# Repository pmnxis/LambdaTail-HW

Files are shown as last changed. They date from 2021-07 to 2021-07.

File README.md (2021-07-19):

# LambdaTail PCB
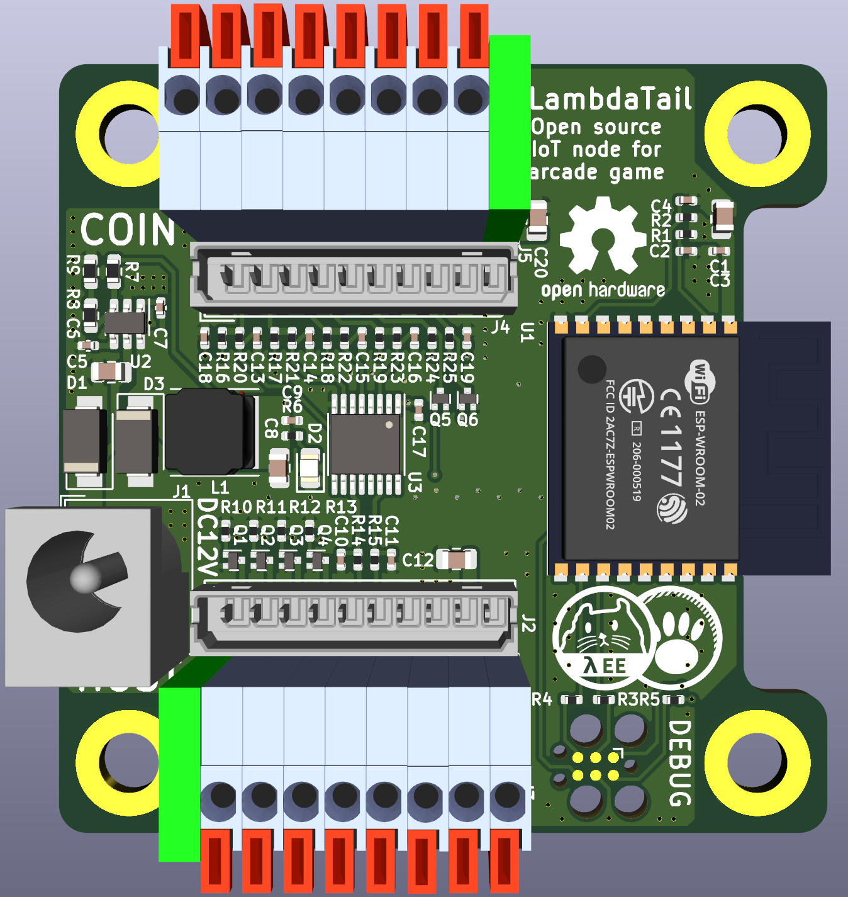
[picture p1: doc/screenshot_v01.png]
ex_screenshot

**Open source IoT node for arcade game**

The goal of this repository is to make **Rust** + **RISC-V** + **Kicad6** based hardware.
And IoT node should be published to large number of devices. So aimed to manufacture with low-cost with less-BOM.

## How works
Monitor vend side device such as paper or coin acceptor at top connector. And then reflect or modify signal to bottom side's connector. 

While monitor vend side, send signal to server or process something.

## Schematics
[Schematic](doc/LambdaTail-HW.pdf)

## Simplified characteristics
| Parameter | Min | Typ | Max | Unit | 
| --- | --- | --- | --- | --- |
| Voltage Power Supply | 4.5 | 12  | 16  | V  |
| Current Consumption  | 50  | 100 | 400 | mA |
| Dimenssion | | 55 x 55 x 16 | | mm

## Dependancy of footprint library
 - https://github.com/pmnxis/Lambda_KICAD5_LIB
 - https://github.com/espressif/kicad-libraries
 - Kicad 5.99 (Kicad 6) and Kicad 5 (legacy) default libraries.

## License
CERN-OHL-S-2.0 for Routing, Gerber, Schematic

Follow to original owner's license for footprint and related things.

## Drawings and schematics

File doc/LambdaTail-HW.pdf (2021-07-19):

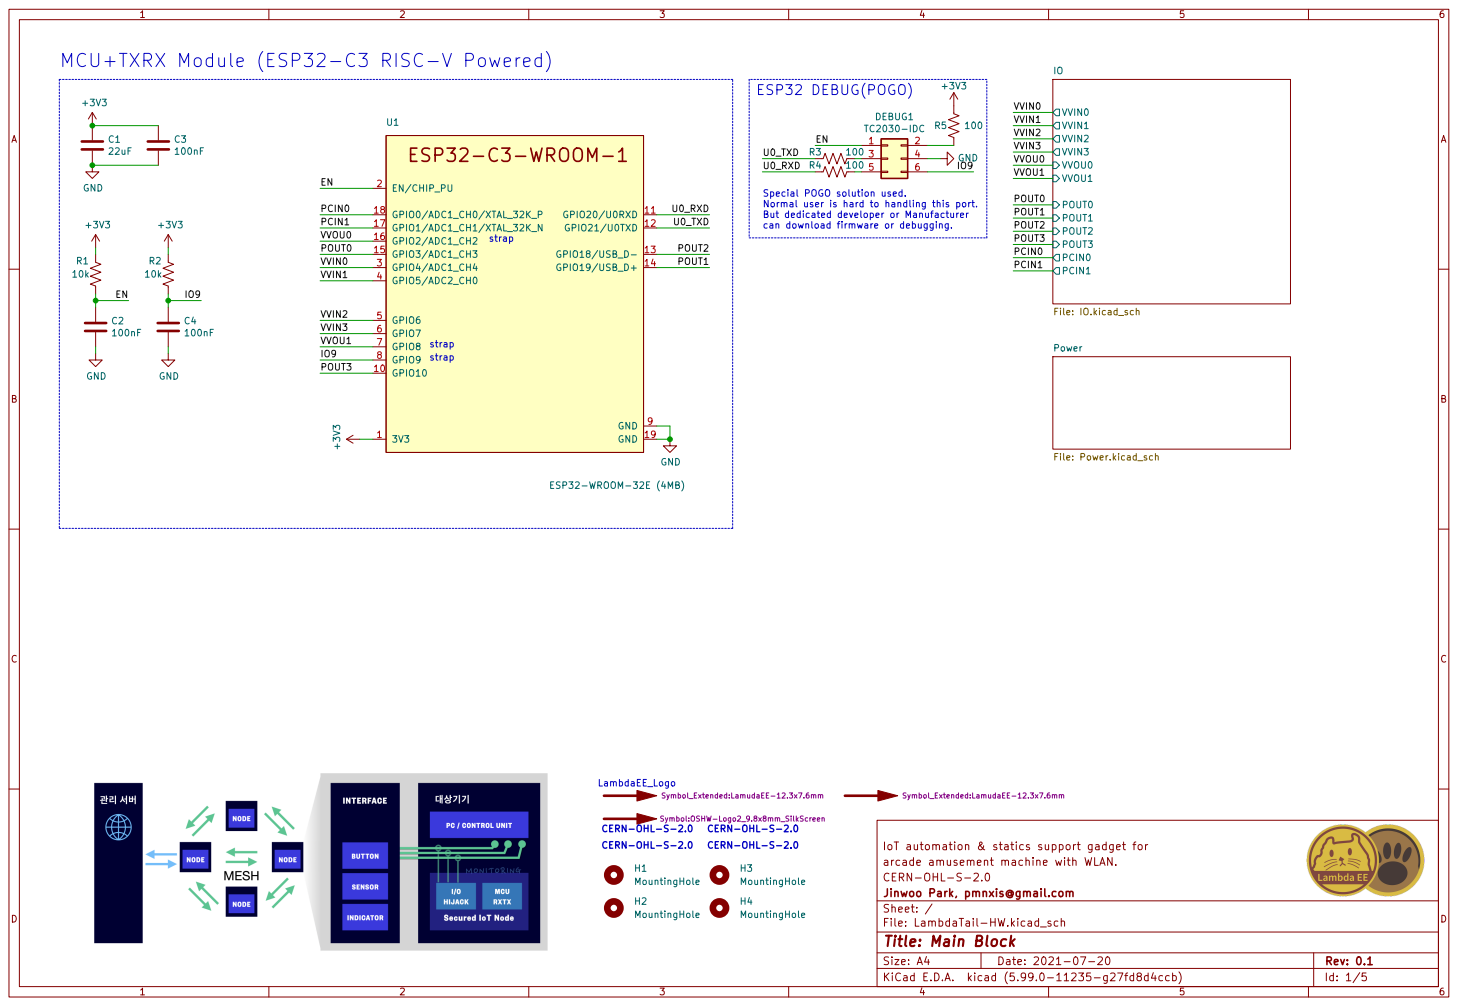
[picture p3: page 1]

strap MCU+TXRX Module (ESP32-C3 RISC-V Powered)

Special POGO solution used.
Normal user is hard to handling this port.
But dedicated developer or Manufacturer

can download firmware or debugging. strap

IoT automation & statics support gadget for arcade amusement machine with WLAN. CERN-OHL-S-2.0

File: LambdaTail-HW.kicad_sch Sheet: / Jinwoo Park, pmnxis@gmail.com

Id: 1/5 Title: Main Block

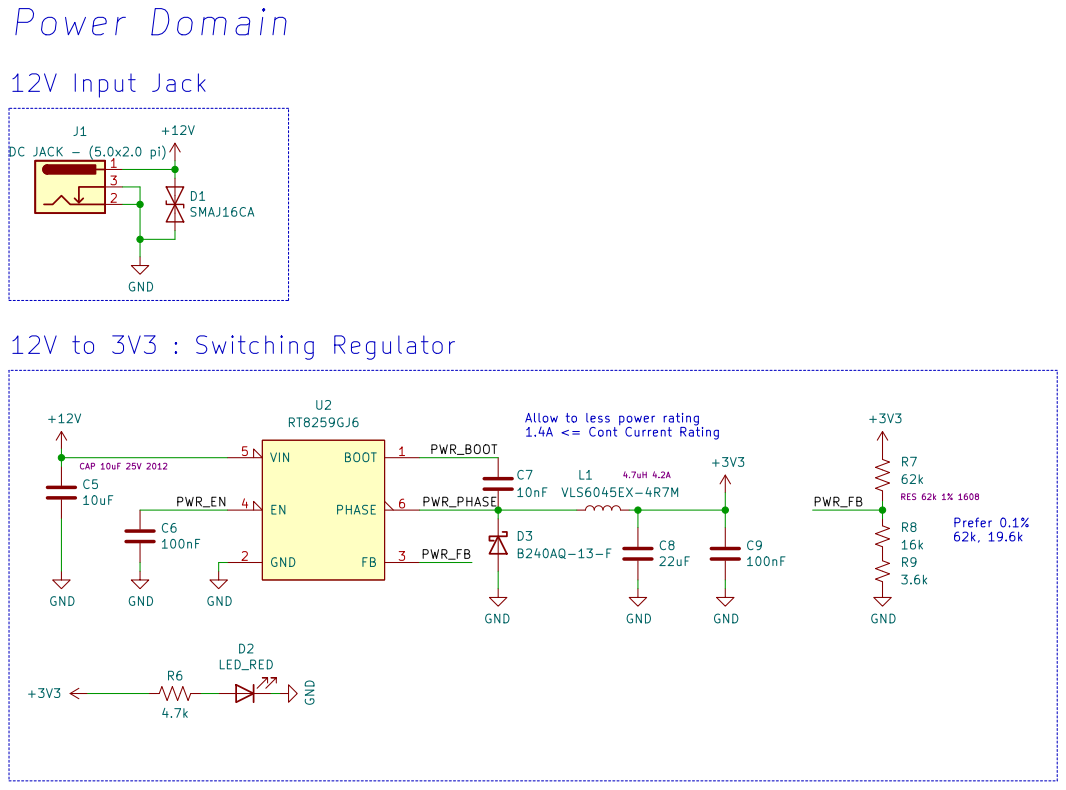
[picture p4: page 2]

Allow to less power rating
1.4A <= Cont Current Rating

IoT automation & statics support gadget for arcade amusement machine with WLAN. CERN-OHL-S-2.0

File: Power.kicad_sch Sheet: /Power/ Jinwoo Park, pmnxis@gmail.com

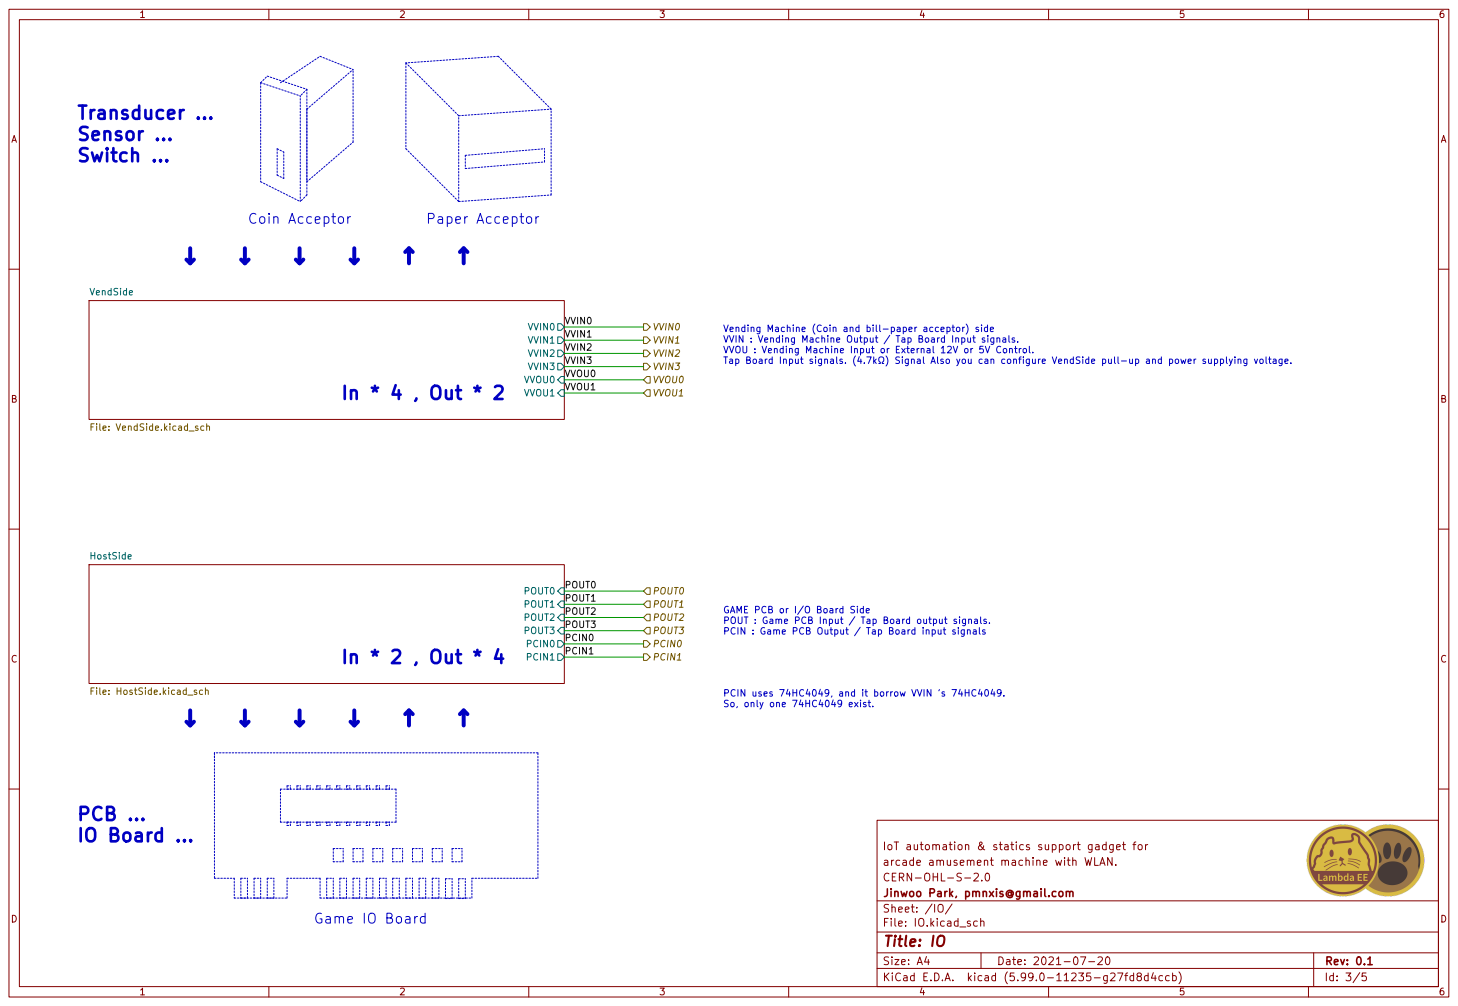
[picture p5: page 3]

VVIN : Vending Machine Output / Tap Board Input signals.
VVOU : Vending Machine Input or External 12V or 5V Control.

PCIN : Game PCB Output / Tap Board input signals PCIN uses 74HC4049, and it borrow VVIN 's 74HC4049. So, only one 74HC4049 exist.

IoT automation & statics support gadget for arcade amusement machine with WLAN. CERN-OHL-S-2.0

File: IO.kicad_sch Sheet: /IO/ Jinwoo Park, pmnxis@gmail.com

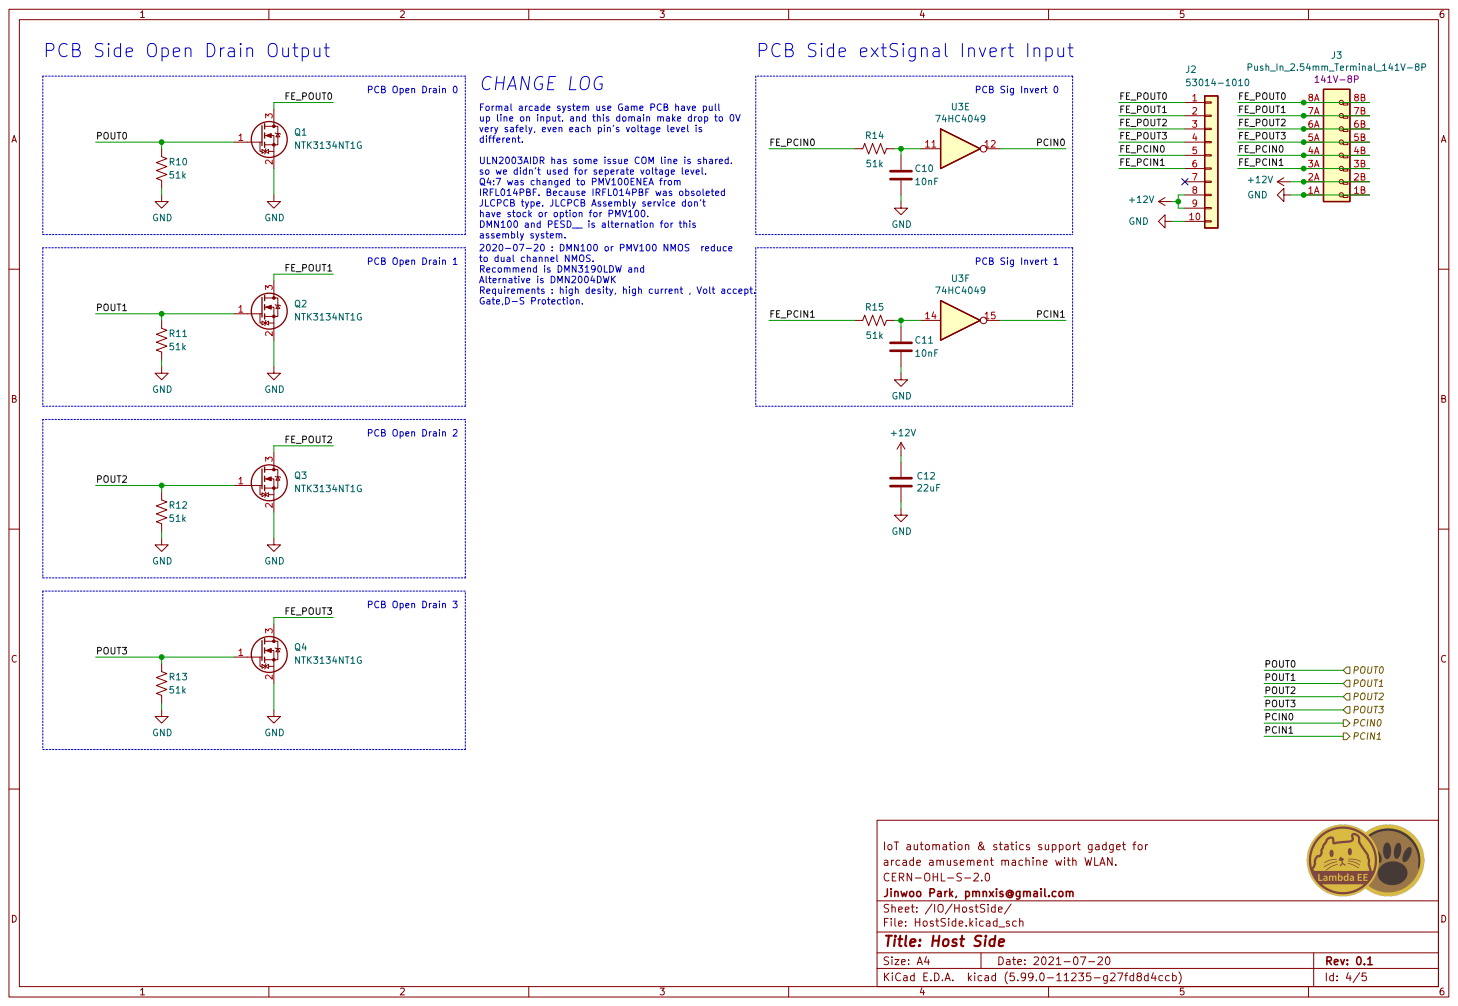
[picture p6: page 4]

to dual channel NMOS. Recommend is DMN3190LDW and Alternative is DMN2004DWK Requirements : high desity, high current , Volt accept. Gate,D-S Protection. PCB Side Open Drain Output

PCB Side extSignal Invert Input

FE_POUT2 FE_POUT3 FE_PCIN0 POUT1 POUT0 PCIN1 Formal arcade system use Game PCB have pull
up line on input. and this domain make drop to 0V
very safely, even each pin's voltage level is different. ULN2003AIDR has some issue COM line is shared. so we didn't used for seperate voltage level.

Q4:7 was changed to PMV100ENEA from
IRFL014PBF. Because IRFL014PBF was obsoleted JLCPCB type. JLCPCB Assembly service don't

have stock or option for PMV100. DMN100 and PESD__ is alternation for this assembly system.

IoT automation & statics support gadget for arcade amusement machine with WLAN. CERN-OHL-S-2.0

File: HostSide.kicad_sch Sheet: /IO/HostSide/ Jinwoo Park, pmnxis@gmail.com

Id: 4/5 Title: Host Side

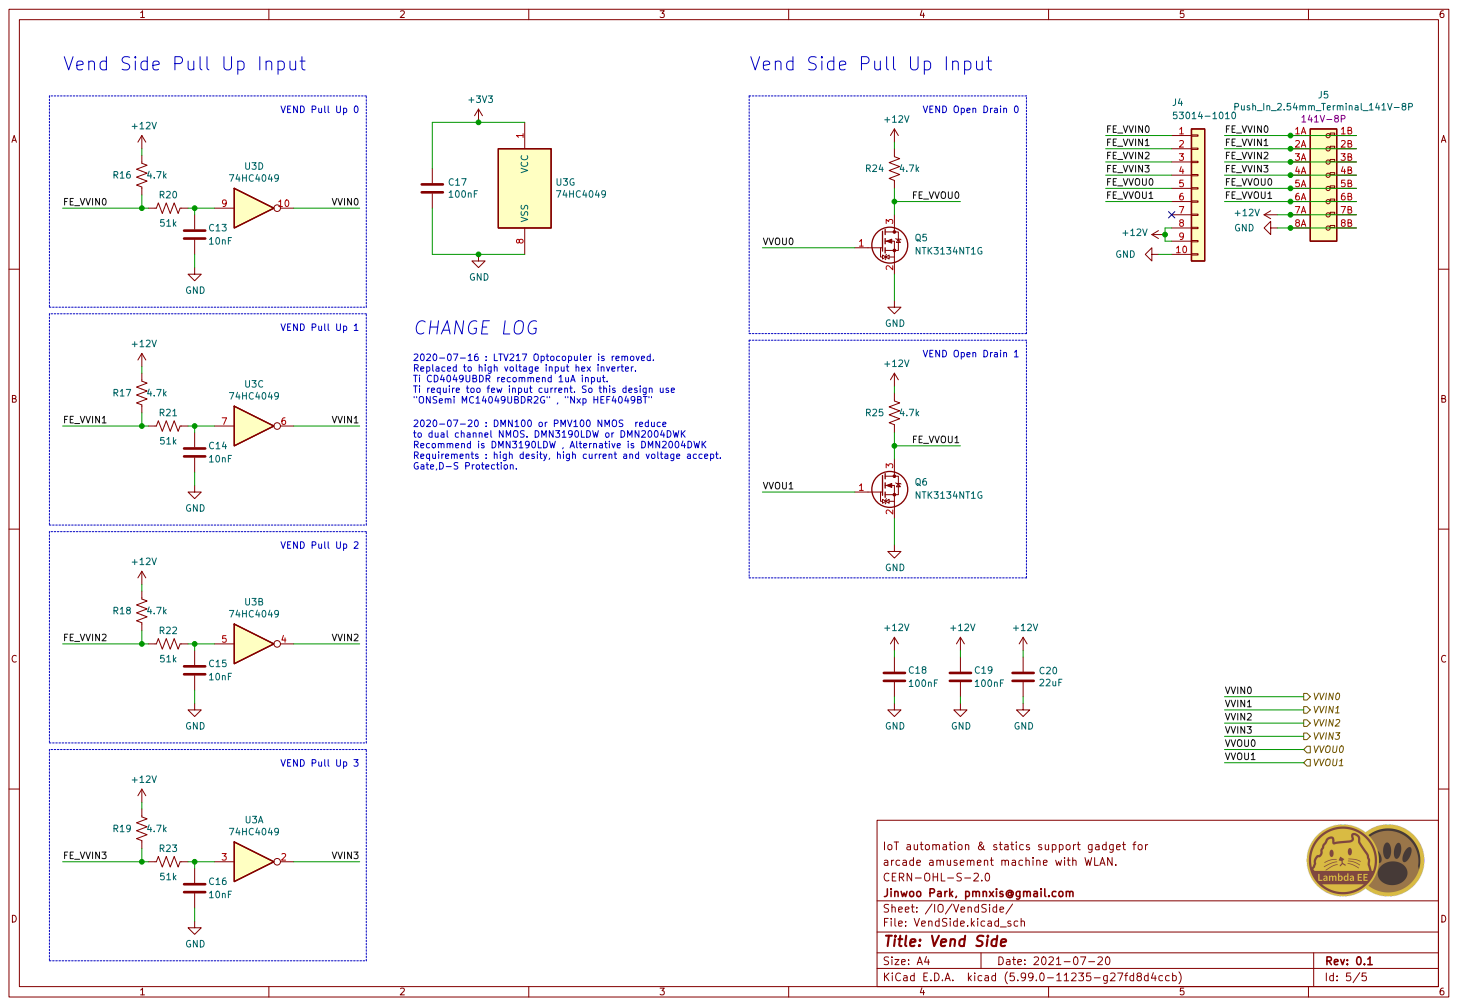
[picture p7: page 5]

Vend Side Pull Up Input

FE_VVIN0 FE_VVIN1 FE_VVIN2 FE_VVOU1 Vend Side Pull Up Input

to dual channel NMOS. DMN3190LDW or DMN2004DWK Recommend is DMN3190LDW , Alternative is DMN2004DWK Requirements : high desity, high current and voltage accept. Gate,D-S Protection. VEND Pull Up 0

2020-07-16 : LTV217 Optocopuler is removed.
Replaced to high voltage input hex inverter.
Ti CD4049UBDR recommend 1uA input.
Ti require too few input current. So this design use
"ONSemi MC14049UBDR2G" , "Nxp HEF4049BT" 2020-07-20 : DMN100 or PMV100 NMOS reduce

IoT automation & statics support gadget for arcade amusement machine with WLAN. CERN-OHL-S-2.0 C14

File: VendSide.kicad_sch Sheet: /IO/VendSide/ Jinwoo Park, pmnxis@gmail.com

Id: 5/5 Title: Vend Side

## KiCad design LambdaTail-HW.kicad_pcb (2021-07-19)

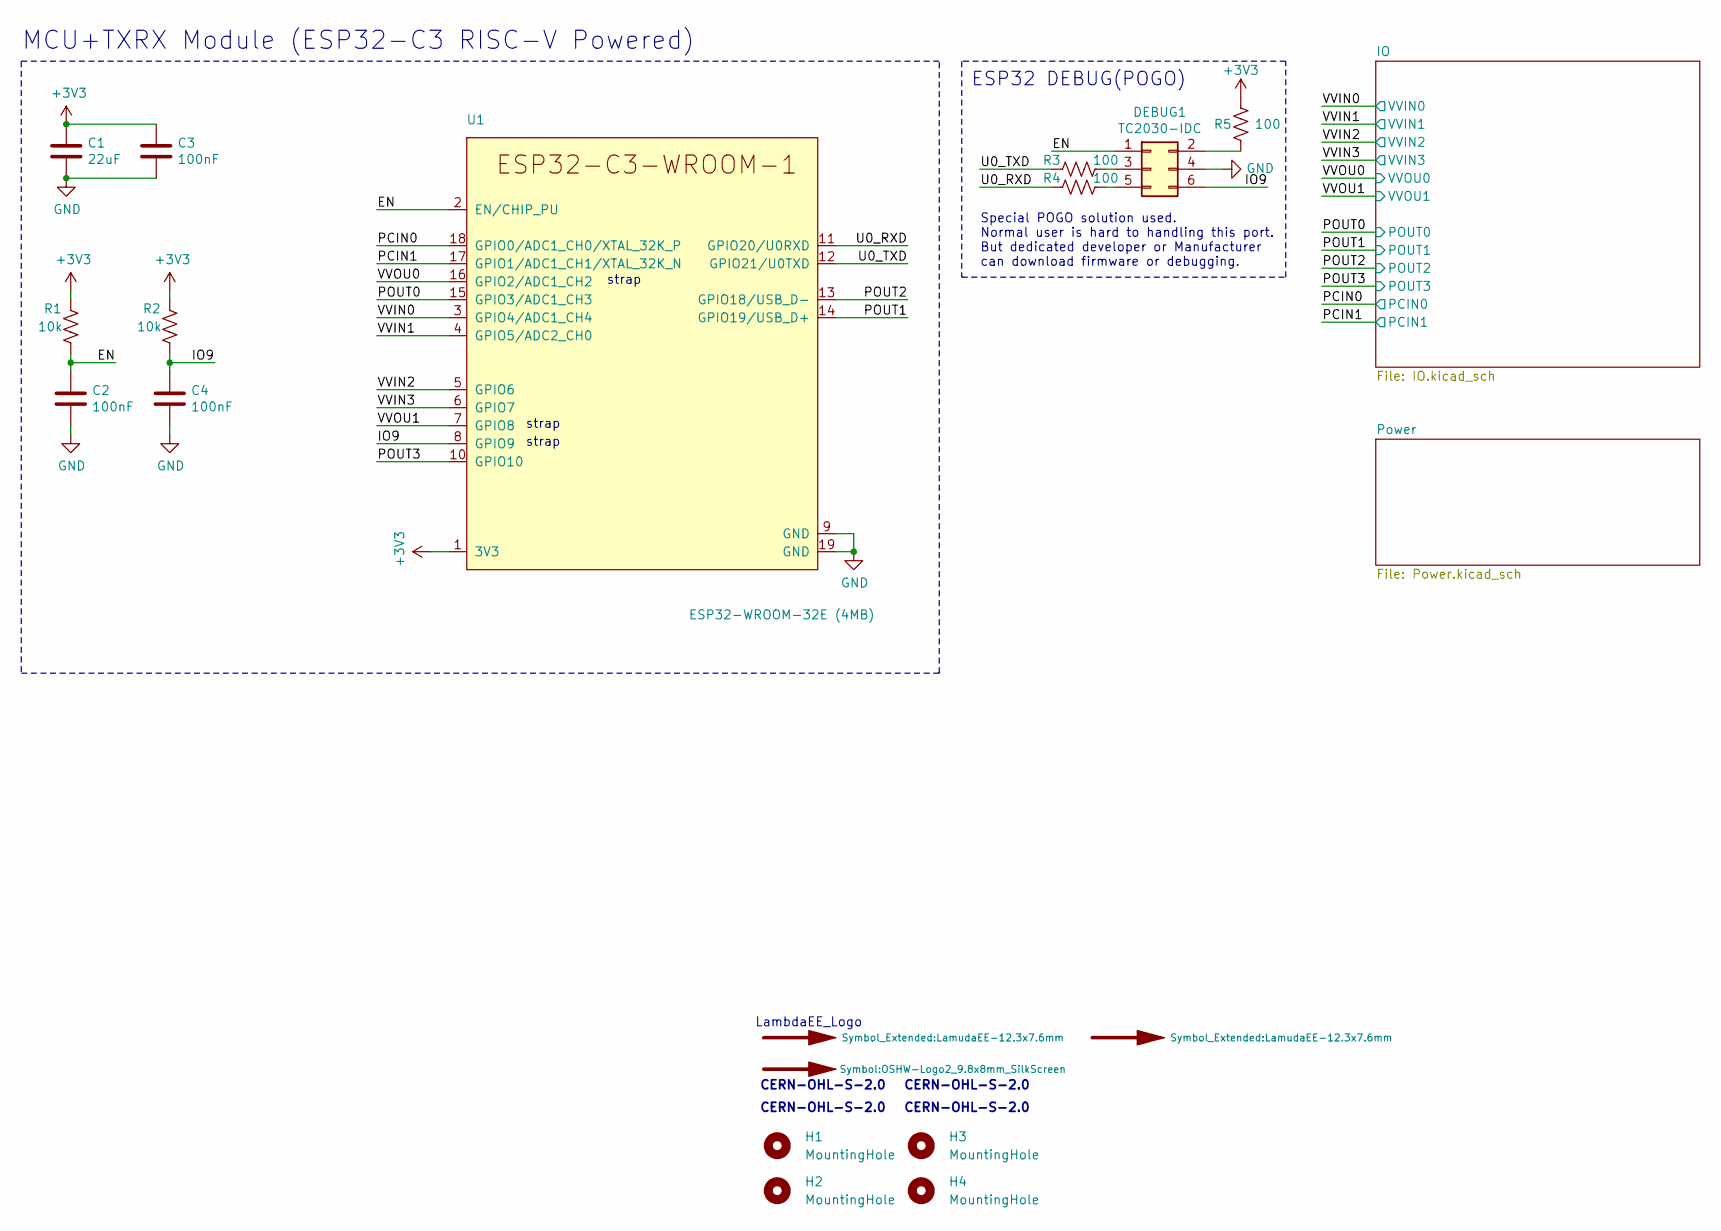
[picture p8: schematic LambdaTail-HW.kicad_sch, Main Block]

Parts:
C1: 22uF; C_0805_2012Metric; MFR.Part# CL21A226MAQNNNE; LCSC Part C45783
C2, C3, C4: 100nF; C_0402_1005Metric; MFR.Part# CL05B104KO5NNNC; LCSC Part C1525
DEBUG1: TC2030-IDC; Tag-Connect_TC2030-IDC-FP_2x03_P1.27mm_Vertical
H1, H2, H3, H4: MountingHole; MountingHole_4.3mm_M4_ISO7380_Pad_TopBottom
R1, R2: 10k; R_0402_1005Metric; MFR.Part# 0402WGF1002TCE; LCSC Part C25744
R3, R4, R5: 100; R_0402_1005Metric; MFR.Part# 0402WGF1000TCE; LCSC Part C25076
SYM1, SYM3: SYM_Arrow_XLarge; LamudaEE-12.3x7.6mm
SYM2: SYM_Arrow_XLarge; OSHW-Logo2_9.8x8mm_SilkScreen
U1: ESP32-WROOM-32E (4MB); ESP32-C3-WROOM-1; MFR.Part# ESP32-WROOM-32E (4MB)

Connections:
+3V3: C1.1, C3.1, R1.1, R2.1, R5.1, U1.1 (3V3); also elsewhere on the board
/EN: C2.1, DEBUG1.1, R1.2, U1.2 (EN/CHIP_PU)
/IO9: C4.1, DEBUG1.6, R2.2, U1.8 (GPIO9)
/PCIN0: U1.18 (GPIO0/ADC1_CH0/XTAL_32K_P); also elsewhere on the board
/PCIN1: U1.17 (GPIO1/ADC1_CH1/XTAL_32K_N); also elsewhere on the board
/POUT0: U1.15 (GPIO3/ADC1_CH3); also elsewhere on the board
/POUT1: U1.14 (GPIO19/USB_D+); also elsewhere on the board
/POUT2: U1.13 (GPIO18/USB_D-); also elsewhere on the board
/POUT3: U1.10 (GPIO10); also elsewhere on the board
/U0_RXD: R4.1, U1.11 (GPIO20/U0RXD)
/U0_TXD: R3.1, U1.12 (GPIO21/U0TXD)
/VVIN0: U1.3 (GPIO4/ADC1_CH4); also elsewhere on the board
/VVIN1: U1.4 (GPIO5/ADC2_CH0); also elsewhere on the board
/VVIN2: U1.5 (GPIO6); also elsewhere on the board
/VVIN3: U1.6 (GPIO7); also elsewhere on the board
/VVOU0: U1.16 (GPIO2/ADC1_CH2); also elsewhere on the board
/VVOU1: U1.7 (GPIO8); also elsewhere on the board
GND: C1.2, C2.2, C3.2, C4.2, DEBUG1.4, U1.9 (GND), U1.19 (GND); also elsewhere on the board
unnamed: DEBUG1.2, R5.2
unnamed: DEBUG1.3, R3.2
unnamed: DEBUG1.5, R4.2

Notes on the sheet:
MCU+TXRX Module (ESP32-C3 RISC-V Powered)
strap
LambdaEE_Logo
CERN-OHL-S-2.0
ESP32 DEBUG(POGO)
Special POGO solution used. Normal user is hard to handling this port. But dedicated developer or Manufacturer can download firmware or debugging.

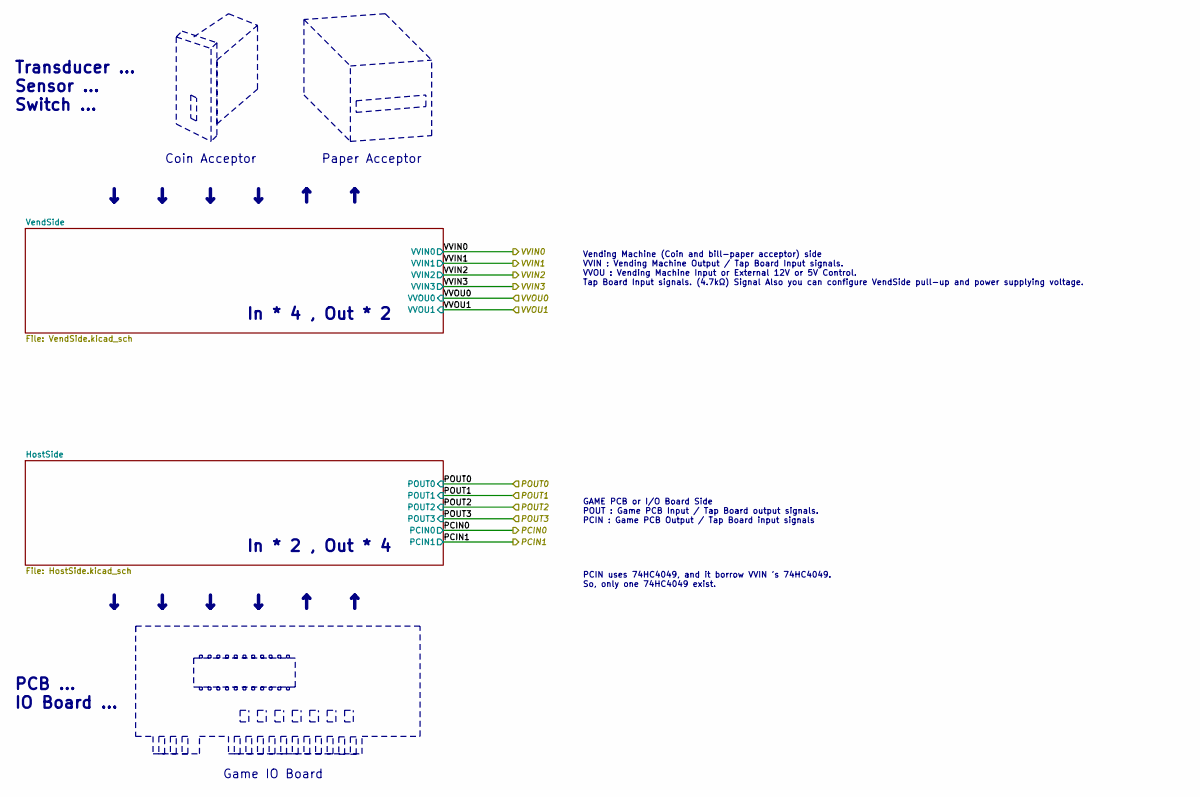
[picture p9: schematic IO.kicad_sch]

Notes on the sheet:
Transducer ... Sensor ... Switch ...
PCB ... IO Board ...
Coin Acceptor
Game IO Board
In * 4 , Out * 2
In * 2 , Out * 4
Paper Acceptor
↓ ↓ ↓ ↓ ↑ ↑
Vending Machine (Coin and bill-paper acceptor) side VVIN : Vending Machine Output / Tap Board Input signals. VVOU : Vending Machine Input or External 12V or 5V Control. Tap Board Input signals. (4.7kΩ) Signal Also you can configure VendSide pull-up and power supplying voltage.
GAME PCB or I/O Board Side POUT : Game PCB Input / Tap Board output signals. PCIN : Game PCB Output / Tap Board input signals
PCIN uses 74HC4049, and it borrow VVIN 's 74HC4049. So, only one 74HC4049 exist.

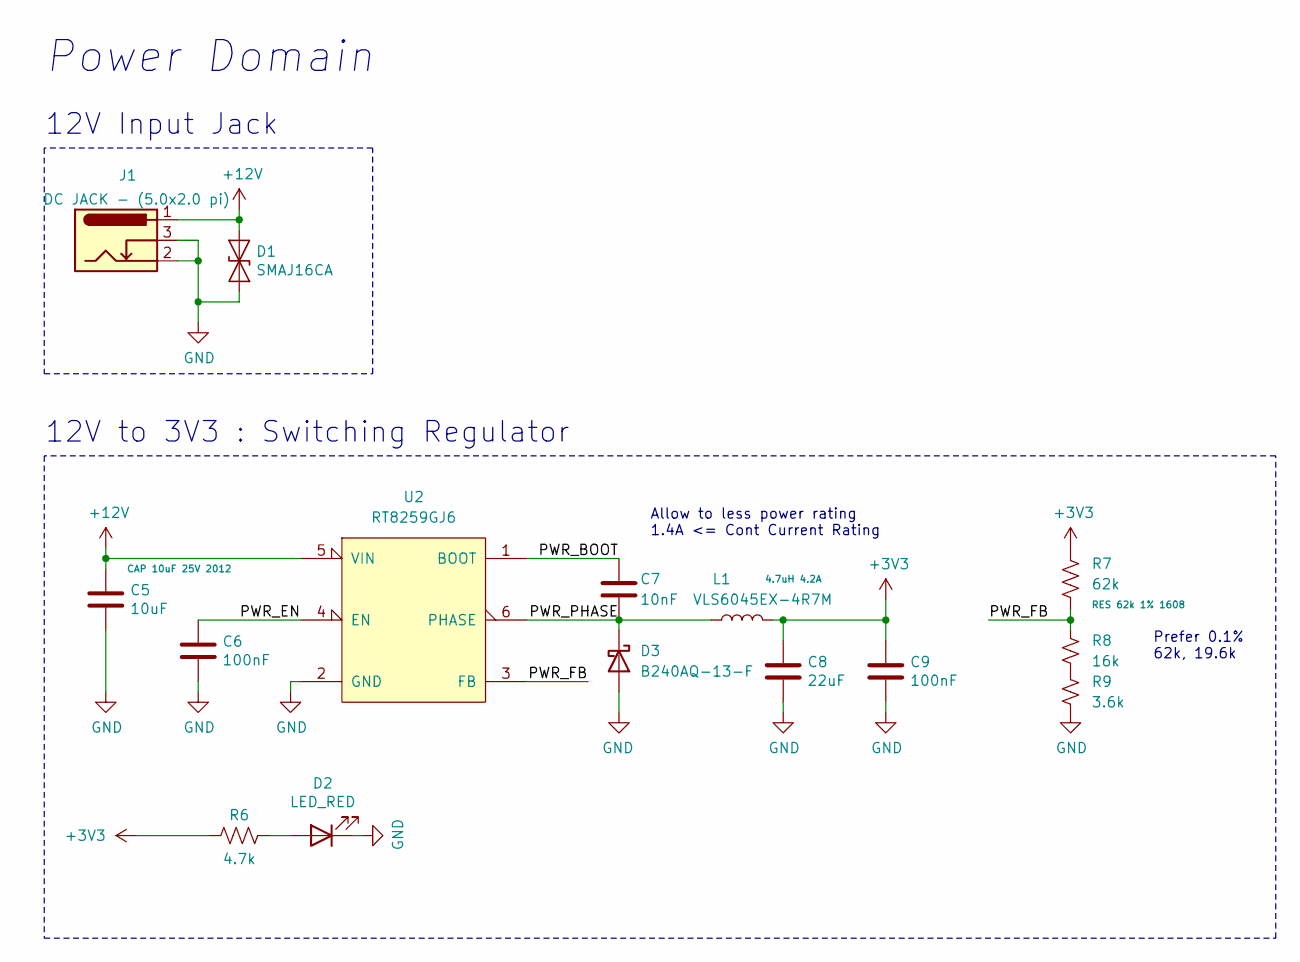
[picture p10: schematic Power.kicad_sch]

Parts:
C5: 10uF; C_0805_2012Metric; MFR.Part# CL21A106KAYNNNE; LCSC Part C15850
C6, C9: 100nF; C_0402_1005Metric; MFR.Part# CL05B104KO5NNNC; LCSC Part C1525
C7: 10nF; C_0402_1005Metric; MFR.Part# CL05B103KB5NNNC; LCSC Part C15195
C8: 22uF; C_0805_2012Metric; MFR.Part# CL21A226MAQNNNE; LCSC Part C45783
D1: SMAJ16CA; D_SMA; MFR.Part# SMAJ16CA; LCSC Part C135970
D2: LED_RED; LED_0805_2012Metric; MFR.Part# FC-2012HRK-620D; LCSC Part C84256
D3: B240AQ-13-F; D_SMA
J1: DC JACK - (5.0x2.0 pi); BarrelJack_General_DC-012-2-5A-2.0mm; MFR.Part# DC-005 5.5-2.0MM; LCSC Part C16214
L1: VLS6045EX-4R7M; L_TDK_VLS6045EX; MFR.Part# VLS6045EX-4R7M; LCSC Part C307880
R6: 4.7k; R_0402_1005Metric; MFR.Part# 0402WGF4701TCE; LCSC Part C25900
R7: 62k; R_0603_1608Metric; MFR.Part# 0603WAF6202T5E; LCSC Part C23221
R8: 16k; R_0603_1608Metric; MFR.Part# 0603WAF1602T5E; LCSC Part C22818
R9: 3.6k; R_0603_1608Metric; MFR.Part# 0603WAF3601T5E; LCSC Part C22980
U2: RT8259GJ6; TSOT-23-6; MFR.Part# RT8259GJ6; LCSC Part C130809

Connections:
+3V3: C8.1, C9.1, L1.2, R6.1, R7.1; also elsewhere on the board
+12V: C5.1, D1.1 (A1), J1.1, U2.5 (VIN); also elsewhere on the board
/Power/PWR_BOOT: C7.1, U2.1 (BOOT)
/Power/PWR_EN: C6.1, U2.4 (EN)
/Power/PWR_FB: R7.2, R8.1, U2.3 (FB)
/Power/PWR_PHASE: C7.2, D3.1 (K), L1.1, U2.6 (PHASE)
GND: C5.2, C6.2, C8.2, C9.2, D1.2 (A2), D2.1 (K), D3.2 (A), J1.2, J1.3, R9.2, U2.2 (GND); also elsewhere on the board
unnamed: D2.2 (A), R6.2
unnamed: R8.2, R9.1

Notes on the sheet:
Power Domain
12V Input Jack
12V to 3V3 : Switching Regulator
Allow to less power rating 1.4A <= Cont Current Rating
Prefer 0.1% 62k, 19.6k

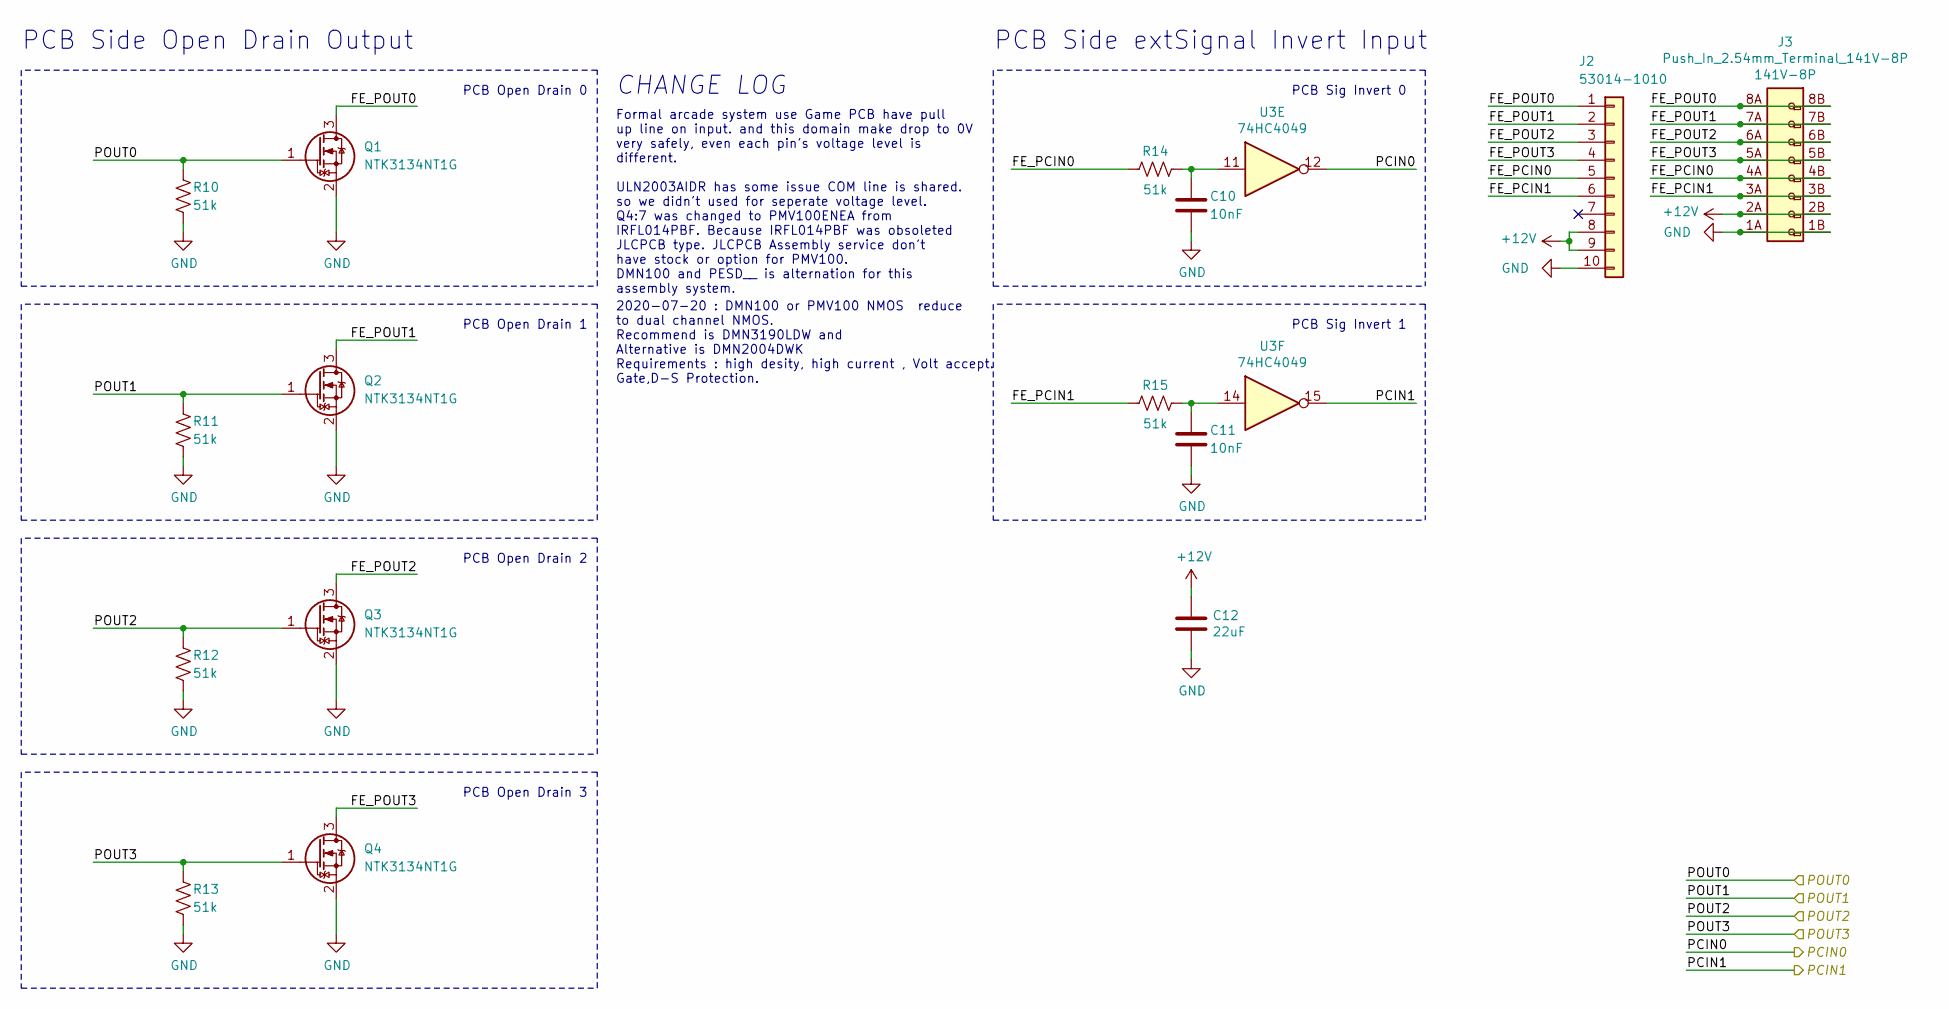
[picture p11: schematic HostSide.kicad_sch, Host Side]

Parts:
C10, C11: 10nF; C_0402_1005Metric; MFR.Part# CL05B103KB5NNNC; LCSC Part C15195
C12: 22uF; C_0805_2012Metric; MFR.Part# CL21A226MAQNNNE; LCSC Part C45783
J2: 53014-1010; Molex_MicroBlade_53014-1000_1x10_P2.00mm_Vertical; MFR.Part# 53014-1010
J3: Push_In_2.54mm_Terminal_141V-8P; TERMINAL_141V-8P; MFR.Part# 141V-8P
Q1, Q2, Q3, Q4: NTK3134NT1G; SOT-723; MFR.Part# NTK3134NT1G; LCSC Part C97777
R10, R11, R12, R13, R14, R15: 51k; R_0402_1005Metric; MFR.Part# 0402WGF5102TCE; LCSC Part C25794
U3: 74HC4049; TSSOP-16_4.4x5mm_P0.65mm; MFR.Part# MC14049UBDTR2GOS

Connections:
+12V: C12.1, J2.8, J2.9, J3.2A, J3.2B; also elsewhere on the board
/IO/HostSide/FE_PCIN0: J2.5, J3.4A, J3.4B, R14.1
/IO/HostSide/FE_PCIN1: J2.6, J3.3A, J3.3B, R15.1
/IO/HostSide/FE_POUT0: J2.1, J3.8A, J3.8B, Q1.3 (D)
/IO/HostSide/FE_POUT1: J2.2, J3.7A, J3.7B, Q2.3 (D)
/IO/HostSide/FE_POUT2: J2.3, J3.6A, J3.6B, Q3.3 (D)
/IO/HostSide/FE_POUT3: J2.4, J3.5A, J3.5B, Q4.3 (D)
/PCIN0: U3.12; also elsewhere on the board
/PCIN1: U3.15; also elsewhere on the board
/POUT0: Q1.1 (G), R10.1; also elsewhere on the board
/POUT1: Q2.1 (G), R11.1; also elsewhere on the board
/POUT2: Q3.1 (G), R12.1; also elsewhere on the board
/POUT3: Q4.1 (G), R13.1; also elsewhere on the board
GND: C10.2, C11.2, C12.2, J2.10, J3.1A, J3.1B, Q1.2 (S), Q2.2 (S), Q3.2 (S), Q4.2 (S), R10.2, R11.2, R12.2, R13.2; also elsewhere on the board
unnamed: C10.1, R14.2, U3.11
unnamed: C11.1, R15.2, U3.14

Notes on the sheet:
PCB Side Open Drain Output
PCB Open Drain 0
PCB Open Drain 1
PCB Open Drain 2
PCB Open Drain 3
CHANGE LOG
Formal arcade system use Game PCB have pull up line on input. and this domain make drop to 0V very safely, even each pin's voltage level is different. ULN2003AIDR has some issue COM line is shared. so we didn't used for seperate voltage level. Q4:7 was changed to PMV100ENEA from IRFL014PBF. Because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
2020-07-20 : DMN100 or PMV100 NMOS reduce to dual channel NMOS. Recommend is DMN3190LDW and Alternative is DMN2004DWK Requirements : high desity, high current , Volt accept. Gate,D-S Protection.
PCB Side extSignal Invert Input
PCB Sig Invert 0
PCB Sig Invert 1

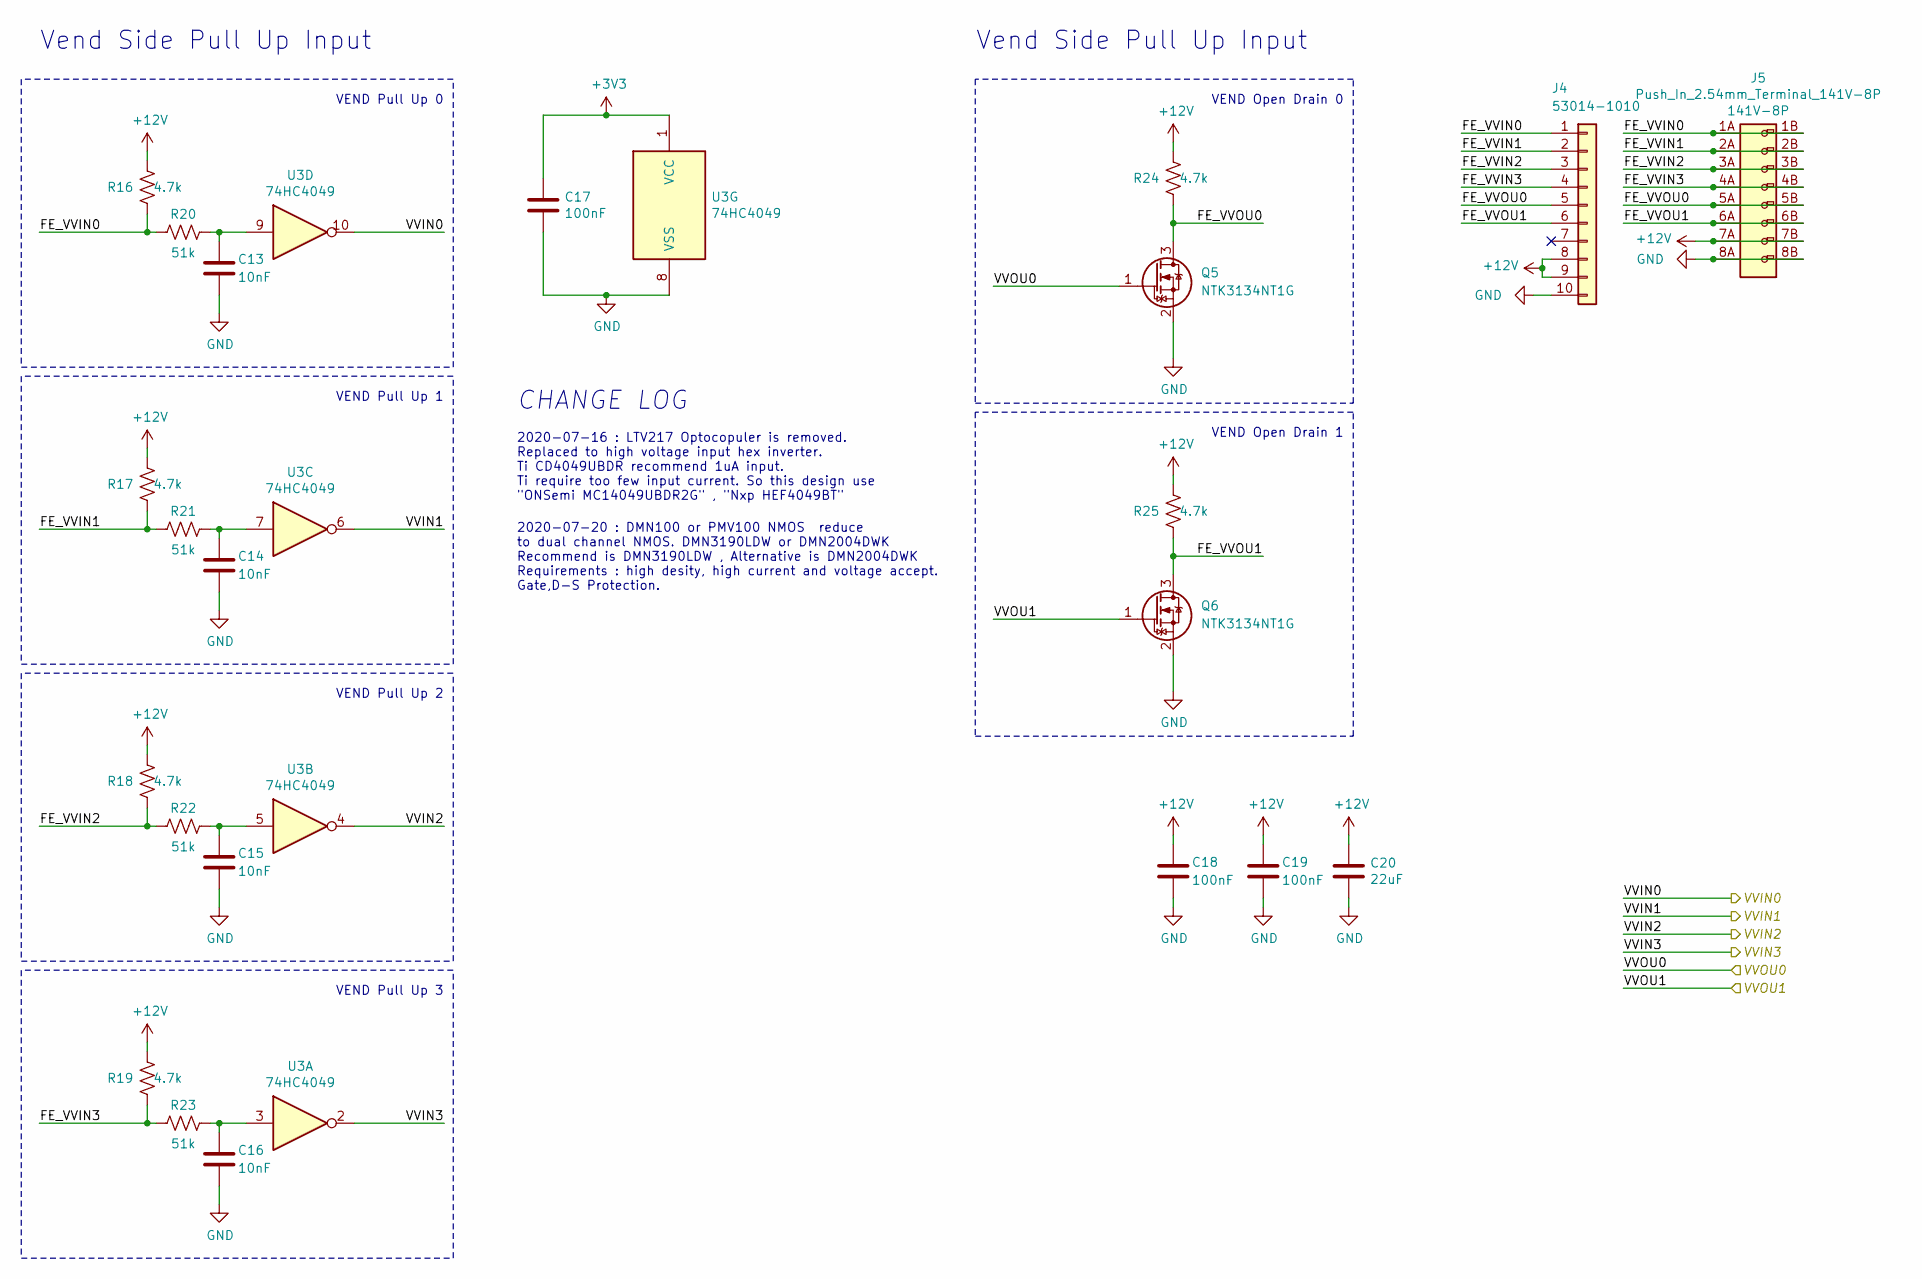
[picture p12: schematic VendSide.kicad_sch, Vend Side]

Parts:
C13, C14, C15, C16: 10nF; C_0402_1005Metric; MFR.Part# CL05B103KB5NNNC; LCSC Part C15195
C17, C18, C19: 100nF; C_0402_1005Metric; MFR.Part# CL05B104KO5NNNC; LCSC Part C1525
C20: 22uF; C_0805_2012Metric; MFR.Part# CL21A226MAQNNNE; LCSC Part C45783
J4: 53014-1010; Molex_MicroBlade_53014-1000_1x10_P2.00mm_Vertical; MFR.Part# 53014-1010
J5: Push_In_2.54mm_Terminal_141V-8P; TERMINAL_141V-8P; MFR.Part# 141V-8P
Q5, Q6: NTK3134NT1G; SOT-723; MFR.Part# NTK3134NT1G; LCSC Part C97777
R16, R17, R18, R19, R24, R25: 4.7k; R_0402_1005Metric; MFR.Part# 0402WGF4701TCE; LCSC Part C25900
R20, R21, R22, R23: 51k; R_0402_1005Metric; MFR.Part# 0402WGF5102TCE; LCSC Part C25794
U3: 74HC4049; TSSOP-16_4.4x5mm_P0.65mm; MFR.Part# MC14049UBDTR2GOS

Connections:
+3V3: C17.1, U3.1 (VCC); also elsewhere on the board
+12V: C18.1, C19.1, C20.1, J4.8, J4.9, J5.7A, J5.7B, R16.2, R17.2, R18.2, R19.2, R24.2, R25.2; also elsewhere on the board
/IO/VendSide/FE_VVIN0: J4.1, J5.1A, J5.1B, R16.1, R20.1
/IO/VendSide/FE_VVIN1: J4.2, J5.2A, J5.2B, R17.1, R21.1
/IO/VendSide/FE_VVIN2: J4.3, J5.3A, J5.3B, R18.1, R22.1
/IO/VendSide/FE_VVIN3: J4.4, J5.4A, J5.4B, R19.1, R23.1
/IO/VendSide/FE_VVOU0: J4.5, J5.5A, J5.5B, Q5.3 (D), R24.1
/IO/VendSide/FE_VVOU1: J4.6, J5.6A, J5.6B, Q6.3 (D), R25.1
/VVIN0: U3.10; also elsewhere on the board
/VVIN1: U3.6; also elsewhere on the board
/VVIN2: U3.4; also elsewhere on the board
/VVIN3: U3.2; also elsewhere on the board
/VVOU0: Q5.1 (G); also elsewhere on the board
/VVOU1: Q6.1 (G); also elsewhere on the board
GND: C13.2, C14.2, C15.2, C16.2, C17.2, C18.2, C19.2, C20.2, J4.10, J5.8A, J5.8B, Q5.2 (S), Q6.2 (S), U3.8 (VSS); also elsewhere on the board
unnamed: C13.1, R20.2, U3.9
unnamed: C14.1, R21.2, U3.7
unnamed: C15.1, R22.2, U3.5
unnamed: C16.1, R23.2, U3.3

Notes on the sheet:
Vend Side Pull Up Input
VEND Pull Up 0
VEND Pull Up 1
VEND Pull Up 2
VEND Pull Up 3
CHANGE LOG
2020-07-16 : LTV217 Optocopuler is removed. Replaced to high voltage input hex inverter. Ti CD4049UBDR recommend 1uA input. Ti require too few input current. So this design use "ONSemi MC14049UBDR2G" , "Nxp HEF4049BT"
2020-07-20 : DMN100 or PMV100 NMOS reduce to dual channel NMOS. DMN3190LDW or DMN2004DWK Recommend is DMN3190LDW , Alternative is DMN2004DWK Requirements : high desity, high current and voltage accept. Gate,D-S Protection.
VEND Open Drain 0
VEND Open Drain 1

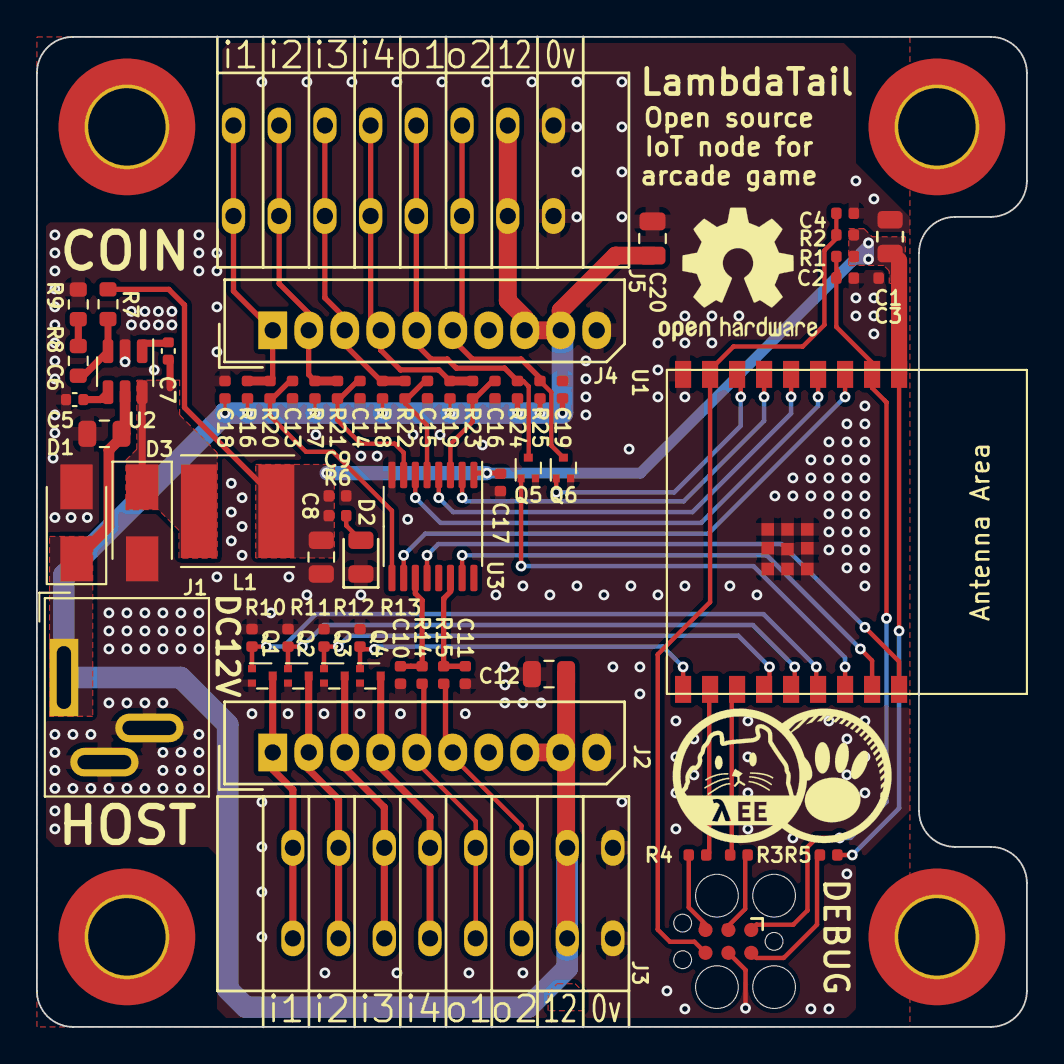
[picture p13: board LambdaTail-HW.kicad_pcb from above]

Board: 2 copper layers, 55.0 x 55.0 mm, 71 parts (1 on the bottom side), 46 nets.
